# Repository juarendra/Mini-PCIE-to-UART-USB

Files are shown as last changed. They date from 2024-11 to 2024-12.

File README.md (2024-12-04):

# Mini-PCIE-to-UART-USB

## Table of Content

* [Product Specsification](#product-specsification)
* [Priview Hardware](#priview-hardware)
* [Documentation](#documentation)
  * [Pinout Diagram](#pinout-diagram)
  * [Dimension](#dimension)
  * [Schematic](#schematic)
* [FAQ](#FAQ)

## Product Spesification
* Mini PCIe Connector
* MIC29302WU as PSU 5V to 3V3
* USB Type C 
* 4 pin JST MOLEX 2.54 as Connector Serial
* LED INDICATOR
* Pin Control RST and WAKEUP

## Priview Hardware
<p align="center">
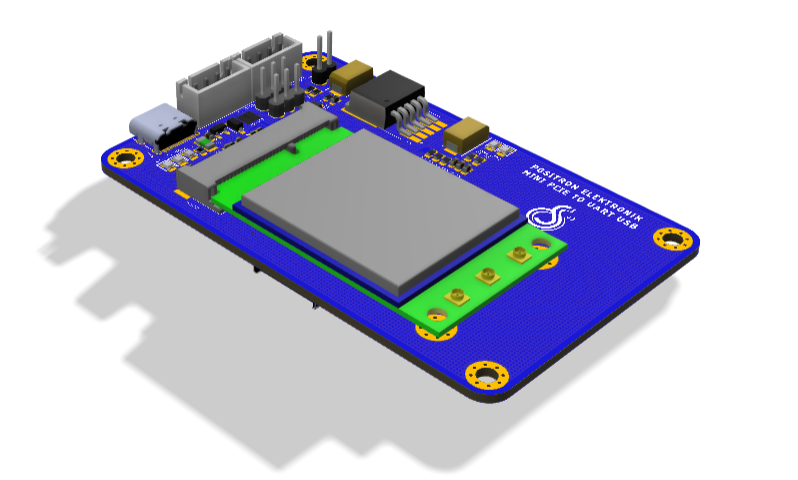
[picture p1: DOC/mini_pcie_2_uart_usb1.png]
  
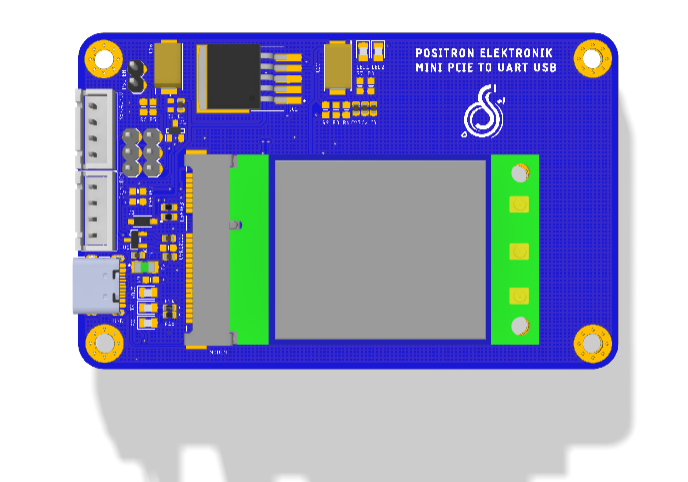
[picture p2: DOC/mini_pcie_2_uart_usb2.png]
  
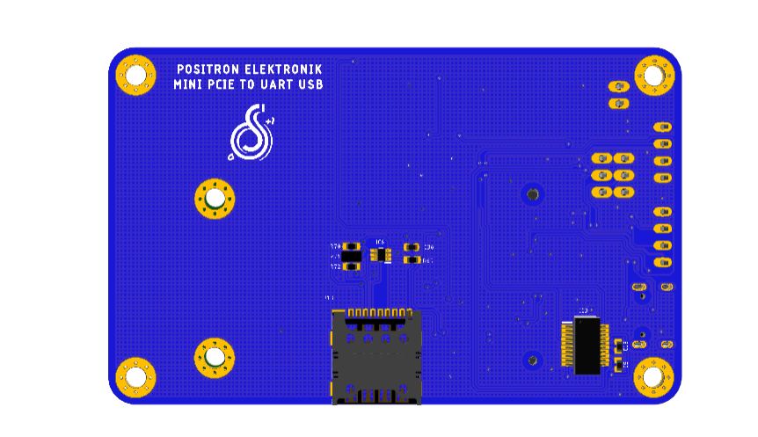
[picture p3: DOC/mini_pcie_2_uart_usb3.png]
  
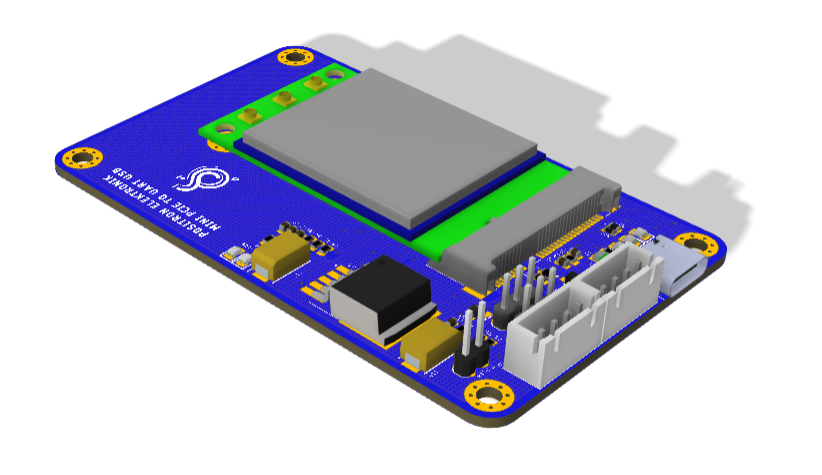
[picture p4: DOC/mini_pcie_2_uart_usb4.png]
  
</p>

## Documentation
### Pinout Diagram
* [Pinout](https://github.com/juarendra/Mini-PCIE-to-UART-USB/blob/main/DOC/Pinout%20Mini-PCIE-to-UART-USB.drawio.pdf)
### Dimension
* [Dimension Board with Component](https://github.com/juarendra/Mini-PCIE-to-UART-USB/blob/main/DOC/DIMENSION%20MINI%20PCIE%202UART%20USB.pdf)
### Schematic
* [Schematic](https://github.com/juarendra/Mini-PCIE-to-UART-USB/blob/main/PDF/mini_pcie_to_uart_usb.pdf)

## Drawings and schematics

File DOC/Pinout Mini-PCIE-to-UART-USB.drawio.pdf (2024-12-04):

# PINOUT CONNECTOR MINI PCIE TO UART USB

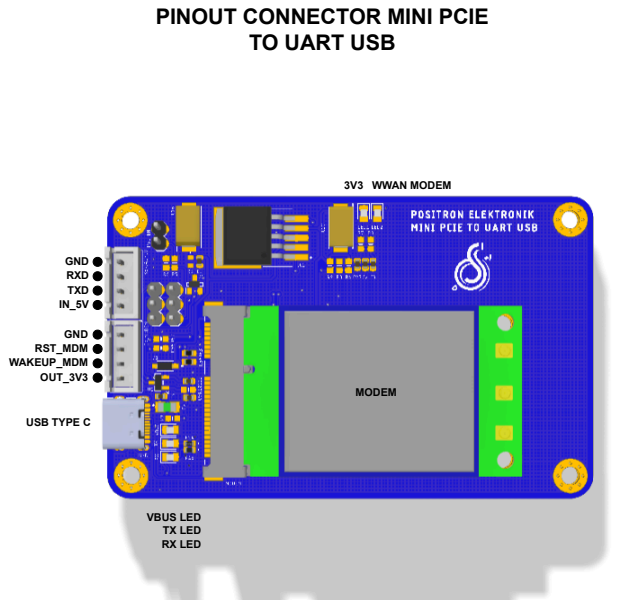
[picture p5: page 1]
GND RXD TXD IN_5V; GND RST_MDM WAKEUP_MDM OUT_3V3; USB TYPE C; VBUS LED TX LED RX LED; 3V3 WWAN MODEM; MODEM

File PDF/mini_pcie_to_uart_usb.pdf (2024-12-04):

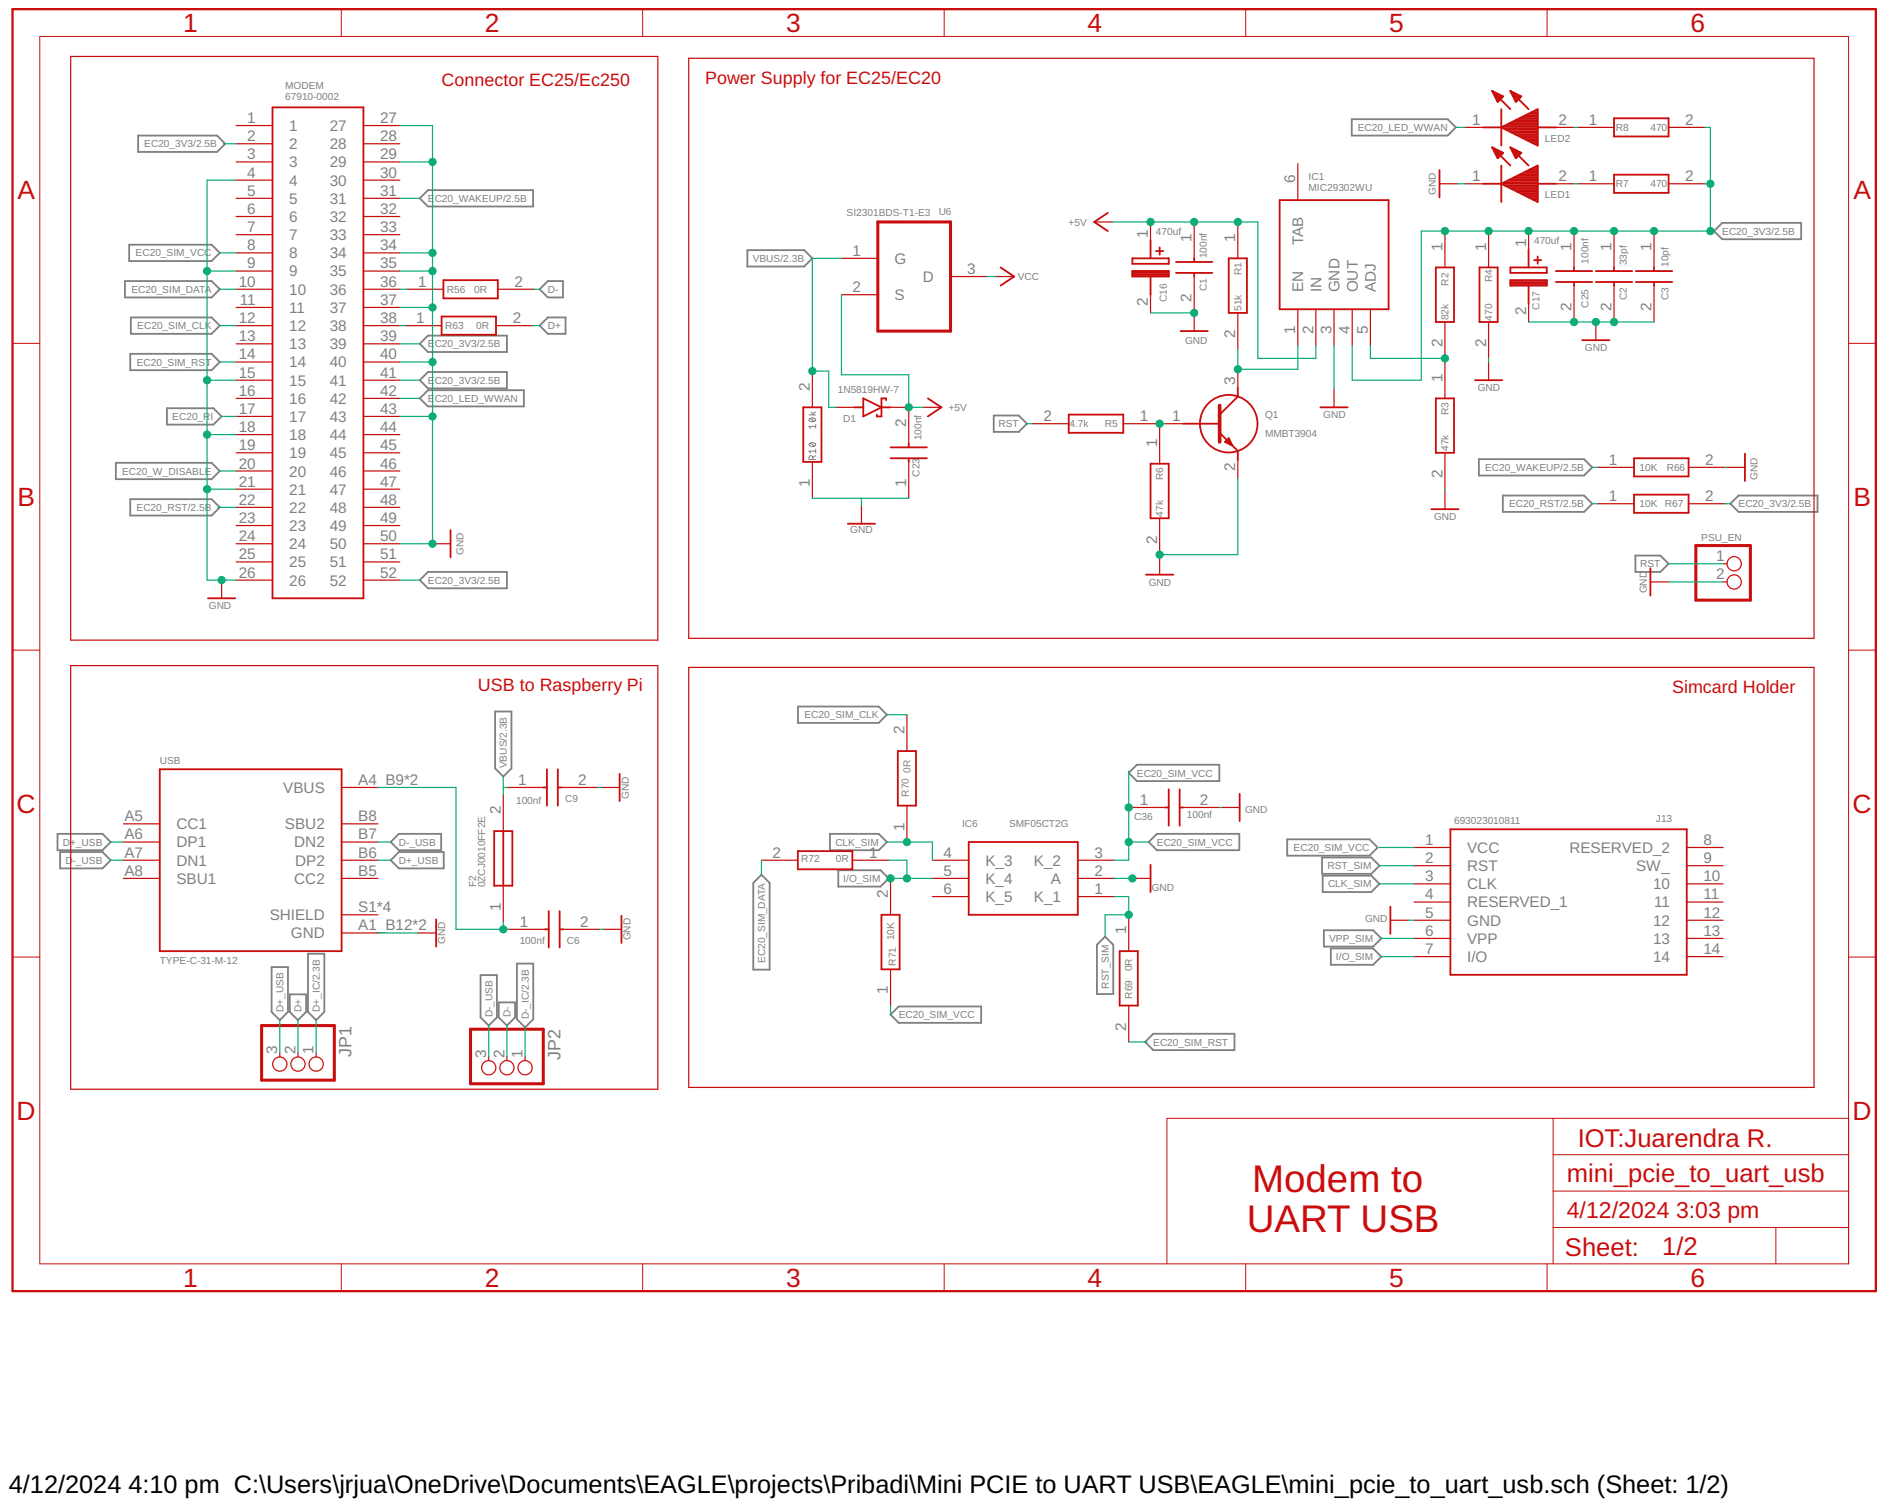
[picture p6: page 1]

4/12/2024 4:10 pm C:\Users\jrjua\OneDrive\Documents\EAGLE\projects\Pribadi\Mini PCIE to UART USB\EAGLE\mini_pcie_to_uart_usb.sch (Sheet: 1/2)

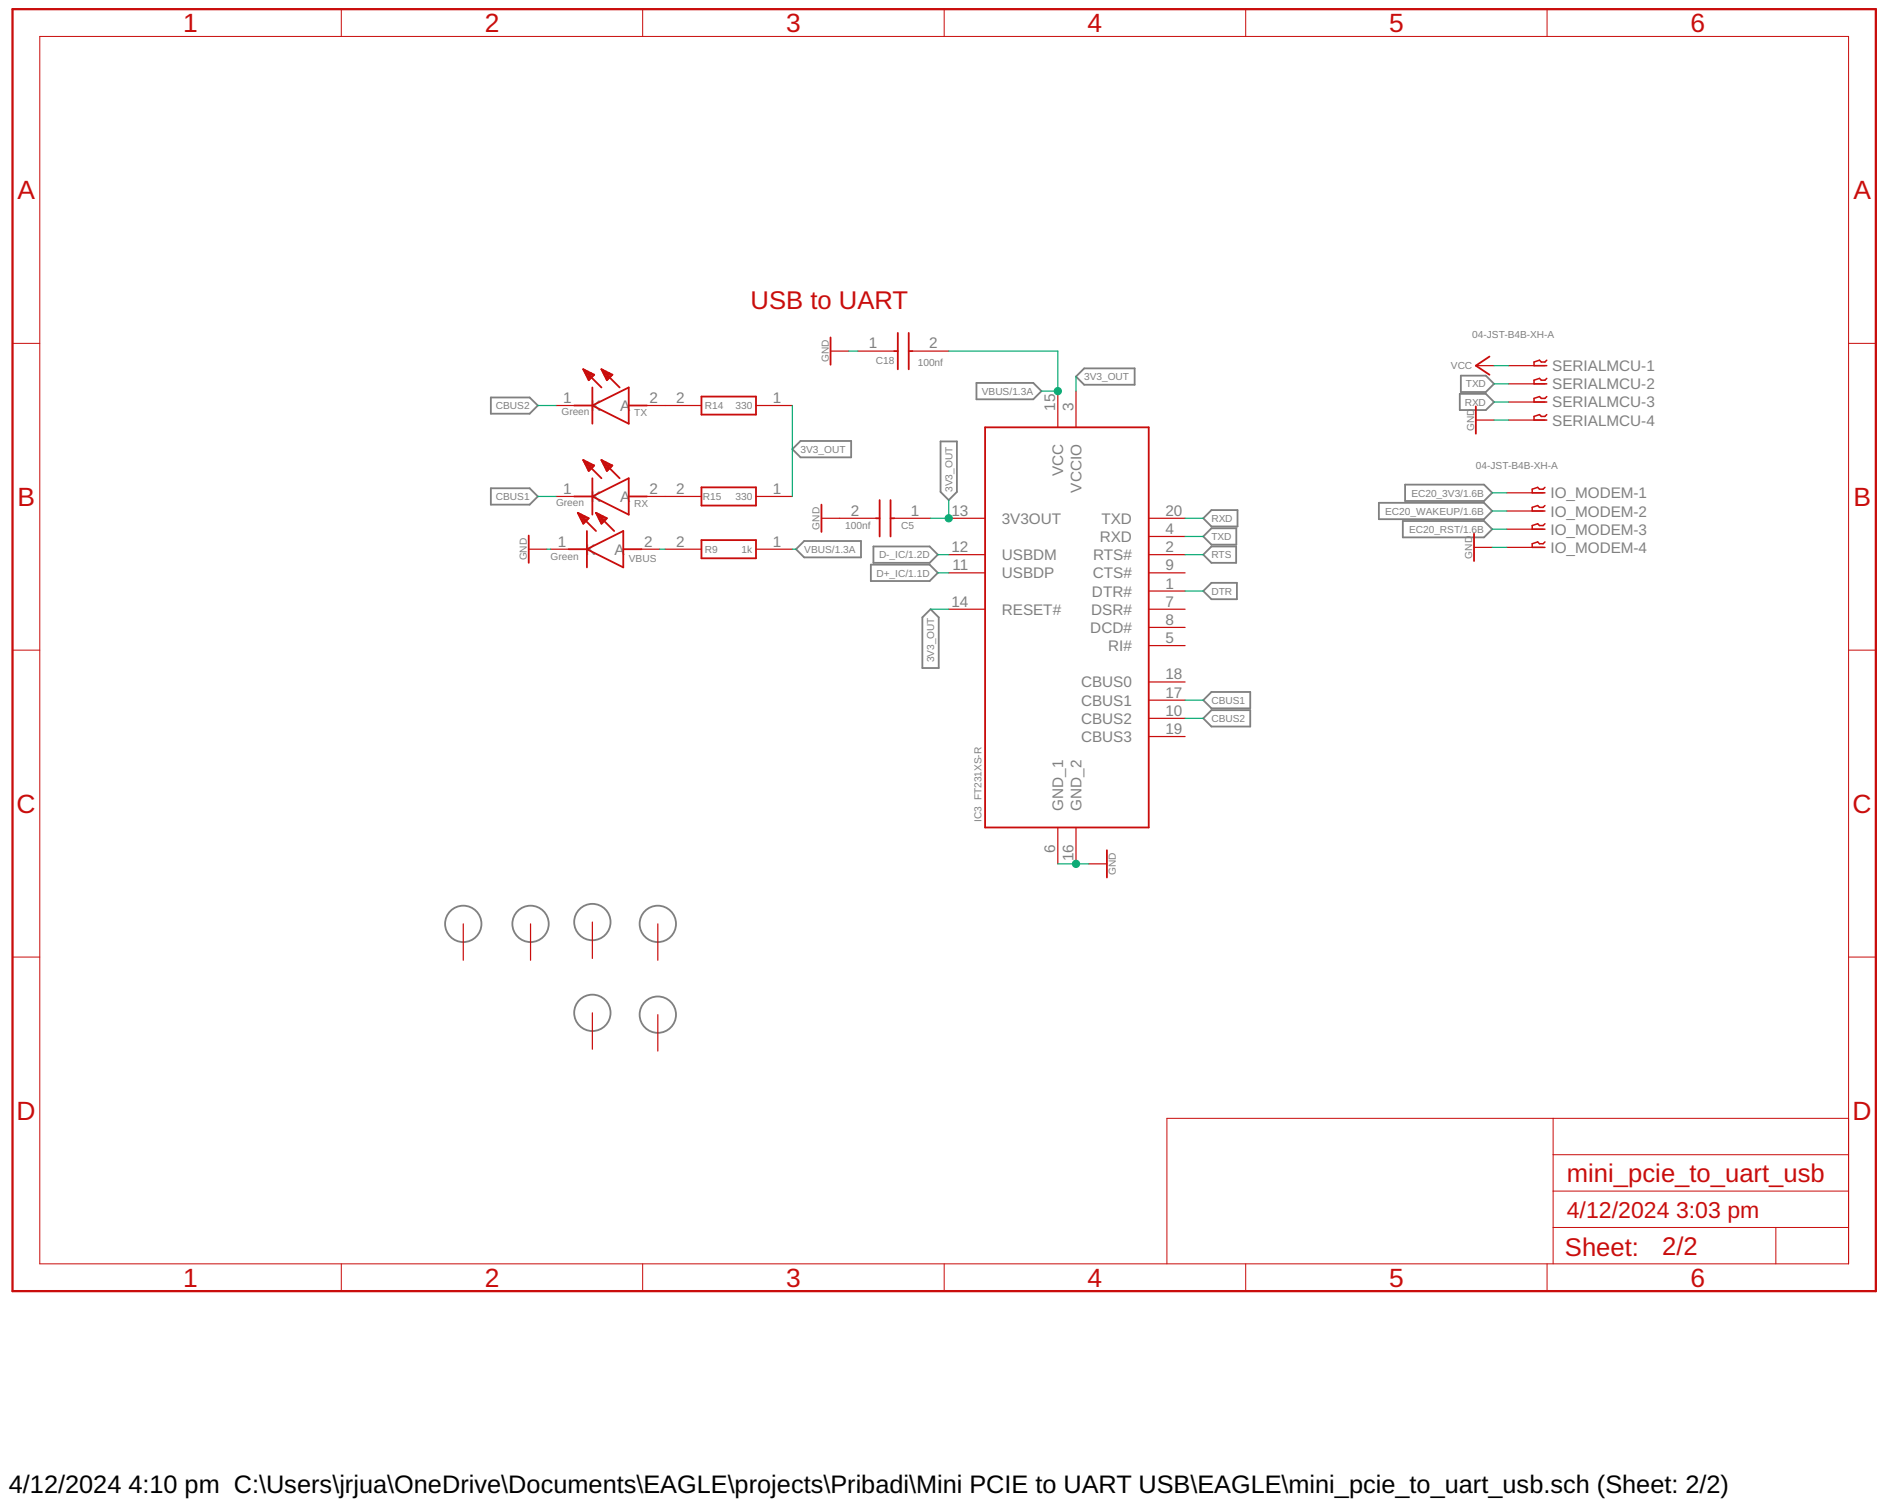
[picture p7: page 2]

SERIALMCU-1 SERIALMCU-2 SERIALMCU-3 SERIALMCU-4

4/12/2024 4:10 pm C:\Users\jrjua\OneDrive\Documents\EAGLE\projects\Pribadi\Mini PCIE to UART USB\EAGLE\mini_pcie_to_uart_usb.sch (Sheet: 2/2)

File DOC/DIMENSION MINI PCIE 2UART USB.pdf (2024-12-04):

# 53.59 Ø3.2 Ø3.2

1.57

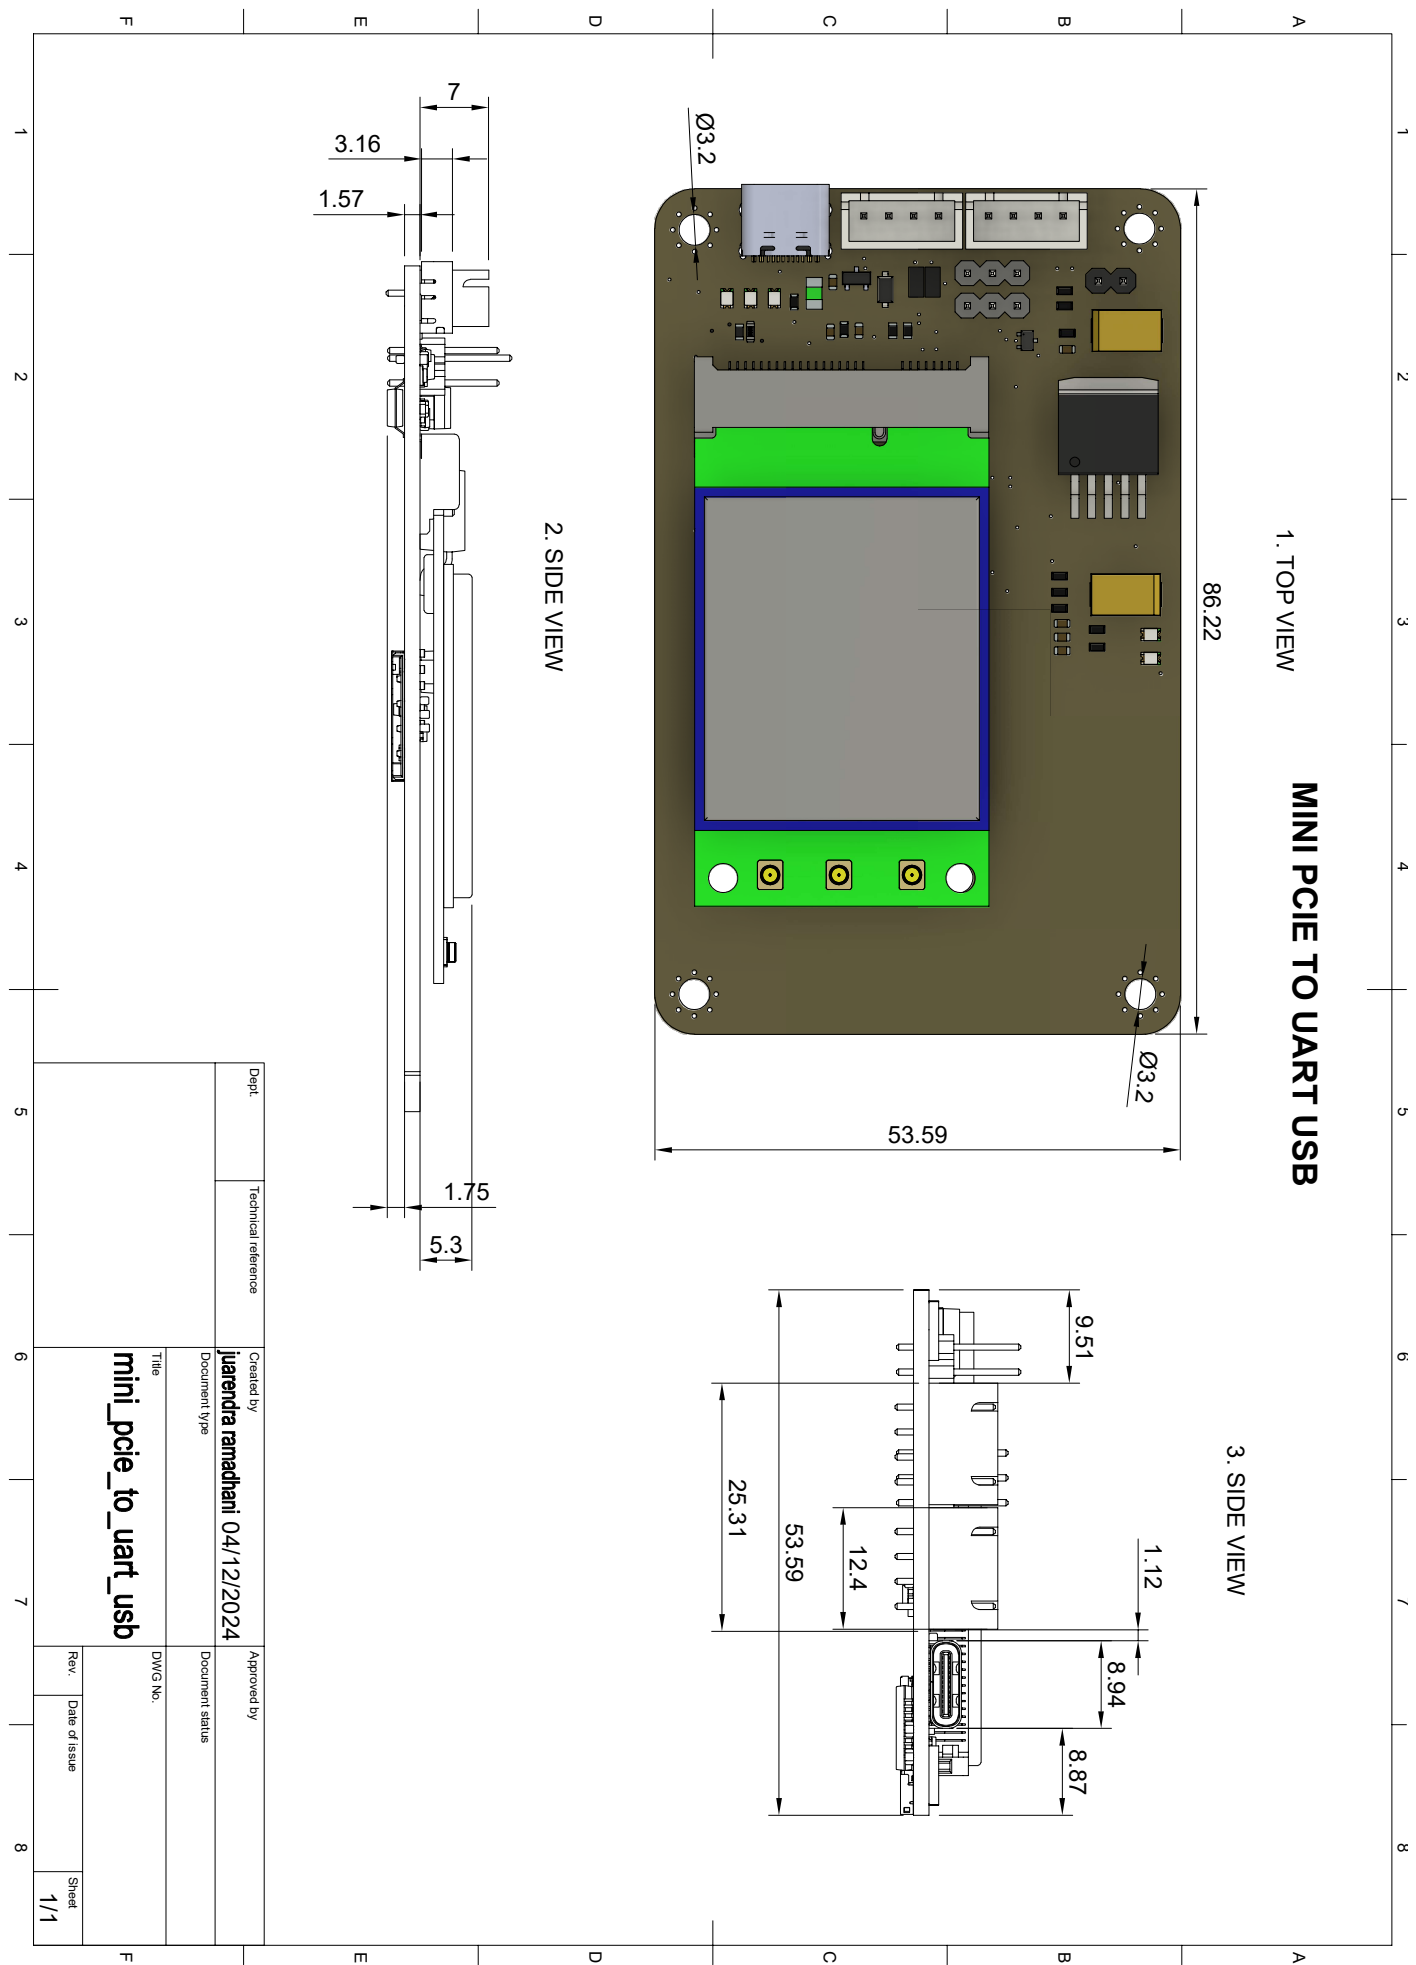
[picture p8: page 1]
9.51 25.31 2. SIDE VIEW; 1. TOP VIEW 3. SIDE VIEW; MINI PCIE TO UART USB

1 A 2 3 4 5 6 7 8 1 2 3 4 5 6 7 8 FEDCB FEDCBA Dept. Technical reference Created by Approved by Title DWG No. Document type Document status Rev. Date of issue Sheet 04/12/2024 1/1 86.22

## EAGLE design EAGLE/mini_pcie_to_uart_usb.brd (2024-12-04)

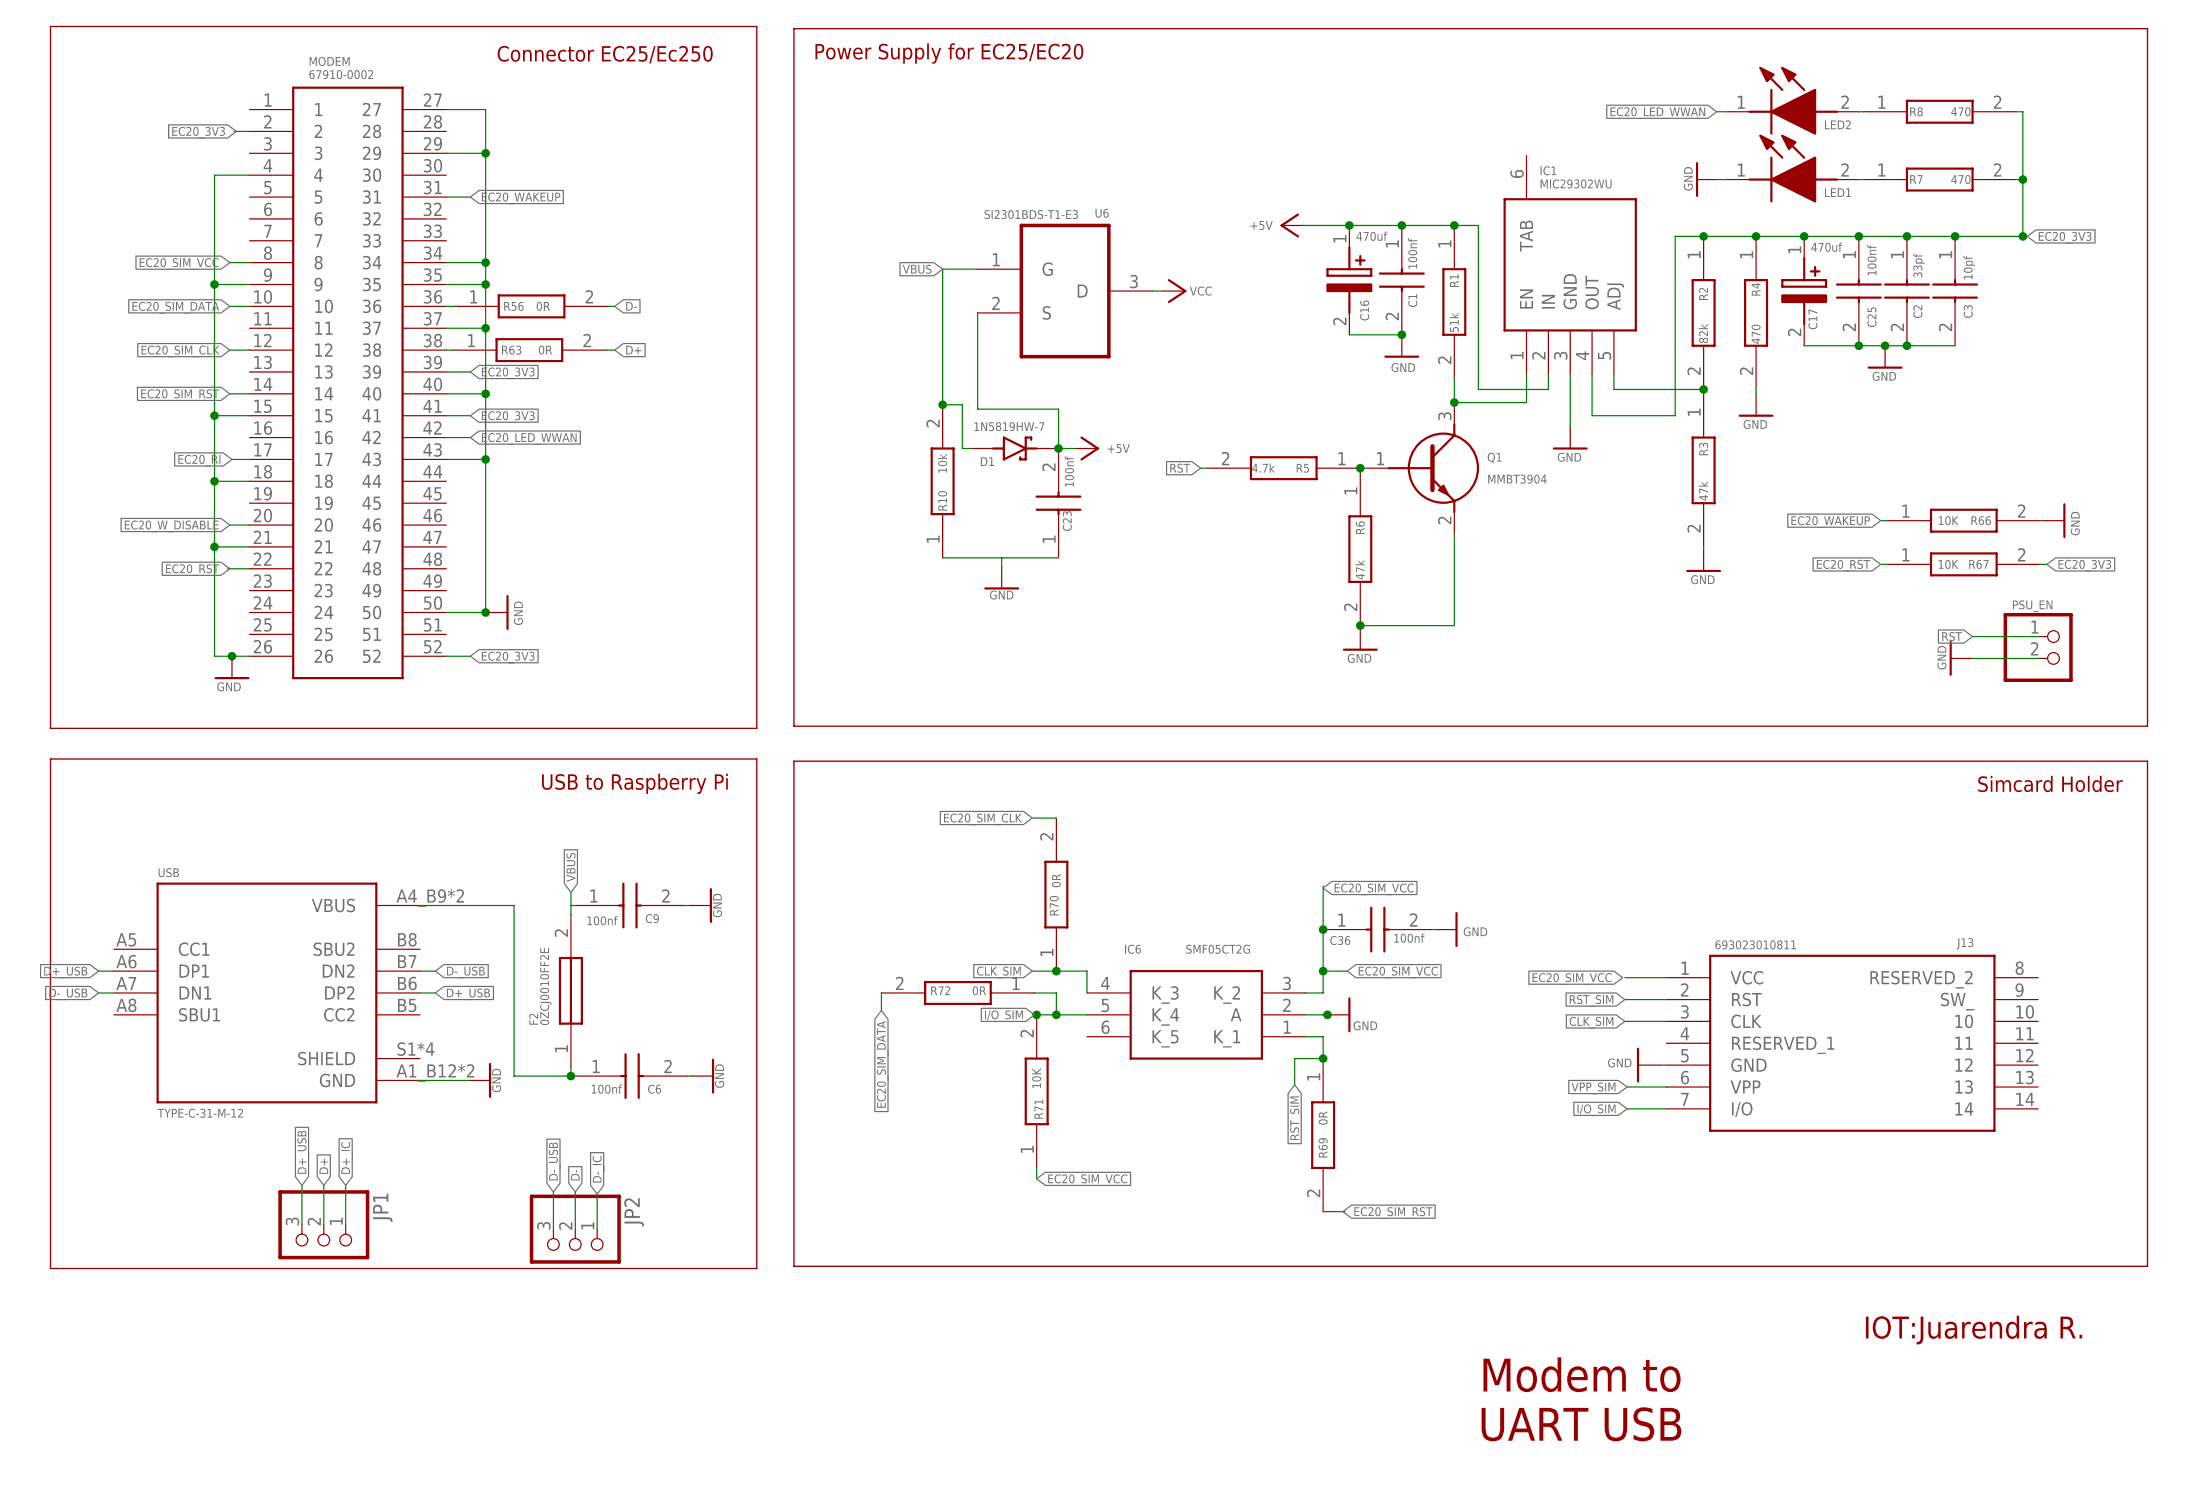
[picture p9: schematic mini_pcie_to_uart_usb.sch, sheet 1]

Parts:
C1, C25, C36: 100nf; CAPC1608X90N
C2: 33pf; CAPC1608X90N
C3: 10pf; CAPC1608X90N
C6, C9, C23: 100nf; CAPC1608X87N
C16, C17: 470uf; CAPPM7343X310N
D1: 1N5819HW-7; SOD3715X145N
F2: 0ZCJ0010FF2E; FUSC3216X75N
IC1: MIC29302WU
IC6: SMF05CT2G; SOT65P210X110-6N
J13: 693023010811
JP1, JP2: PINHD-1X3; 1X03
LED1, LED2: HSMR-C170-R0000; LEDC2012X90N
MODEM: 67910-0002; 67910-5700
PSU_EN: PINHD-1X2; 1X02
Q1: MMBT3904; SOT95P240X120-3N
R1: 51k; ERJP03_PA3_(0603)
R2: 82k; RESC1609X55N
R3, R6: 47k; RESC1609X55N
R4, R7, R8: 470; RESC1609X55N
R5: 4.7k; RESC1609X55N
R10: 10k; RESC1608X55N
R56, R63, R69, R70, R72: 0R; RESC1608X55N
R66, R67, R71: 10K; RESC1608X55N
U6: SI2301BDS-T1-E3; SOT95P237X112-3N
USB: TYPE-C-31-M-12; HRO_TYPE-C-31-M-12

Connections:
+5V: C1.1, C16.1 (+), C23.2, D1.C (K), IC1.2 (IN), R1.1, U6.2 (S)
CLK_SIM: IC6.4 (K_3), J13.3 (CLK), R70.1
D+: JP1.2, R63.2
D+_IC: JP1.1; also elsewhere on the board
D+_USB: JP1.3, USB.A6 (DP1), USB.B6 (DP2)
D-: JP2.2, R56.2
D-_IC: JP2.1; also elsewhere on the board
D-_USB: JP2.3, USB.A7 (DN1), USB.B7 (DN2)
EC20_3V3: C2.1, C3.1, C17.1 (+), C25.1, IC1.4 (OUT), MODEM.2, MODEM.39, MODEM.41, MODEM.52, R2.1, R4.1, R7.2, R8.2, R67.2; also elsewhere on the board
EC20_LED_WWAN: LED2.1 (K), MODEM.42
EC20_RI: MODEM.17
EC20_RST: MODEM.22, R67.1; also elsewhere on the board
EC20_SIM_CLK: MODEM.12, R70.2
EC20_SIM_DATA: MODEM.10, R72.2
EC20_SIM_RST: MODEM.14, R69.2
EC20_SIM_VCC: C36.1, IC6.3 (K_2), J13.1 (VCC), MODEM.8, R71.1
EC20_WAKEUP: MODEM.31, R66.1; also elsewhere on the board
EC20_W_DISABLE: MODEM.20
GND: C1.2, C2.2, C3.2, C6.2, C9.2, C16.2 (-), C17.2 (-), C23.1, C25.2, C36.2, IC1.3 (GND), IC6.2 (A), J13.5 (GND), LED1.1 (K), MODEM.4, MODEM.9, MODEM.15, MODEM.18, MODEM.21, MODEM.26, MODEM.27, MODEM.29, MODEM.34, MODEM.35, MODEM.37, MODEM.40, MODEM.43, MODEM.50, PSU_EN.2, Q1.2 (E), R3.2, R4.2, R6.2, R10.1, R66.2, USB.A1_B12 (GND), USB.B1_A12 (GND); also elsewhere on the board
I/O_SIM: IC6.5 (K_4), J13.7 (I/O), R71.2, R72.1
unnamed: IC1.1 (EN), Q1.3 (C), R1.2
unnamed: IC1.5 (ADJ), R2.2, R3.1
unnamed: Q1.1 (B), R5.1, R6.1
unnamed: LED1.2 (A), R7.1
unnamed: C6.1, F2.1, USB.A4_B9 (VBUS), USB.B4_A9 (VBUS)
unnamed: LED2.2 (A), R8.1
unnamed: MODEM.38, R63.1
unnamed: MODEM.36, R56.1
RST: PSU_EN.1, R5.2
RST_SIM: IC6.1 (K_1), J13.2 (RST), R69.1
VBUS: C9.1, D1.A, F2.2, R10.2, U6.1 (G); also elsewhere on the board
VCC: U6.3 (D); also elsewhere on the board
VPP_SIM: J13.6 (VPP)

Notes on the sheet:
Modem to UART USB
IOT:Juarendra R.
USB to Raspberry Pi
Simcard Holder
Power Supply for EC25/EC20
Connector EC25/Ec250

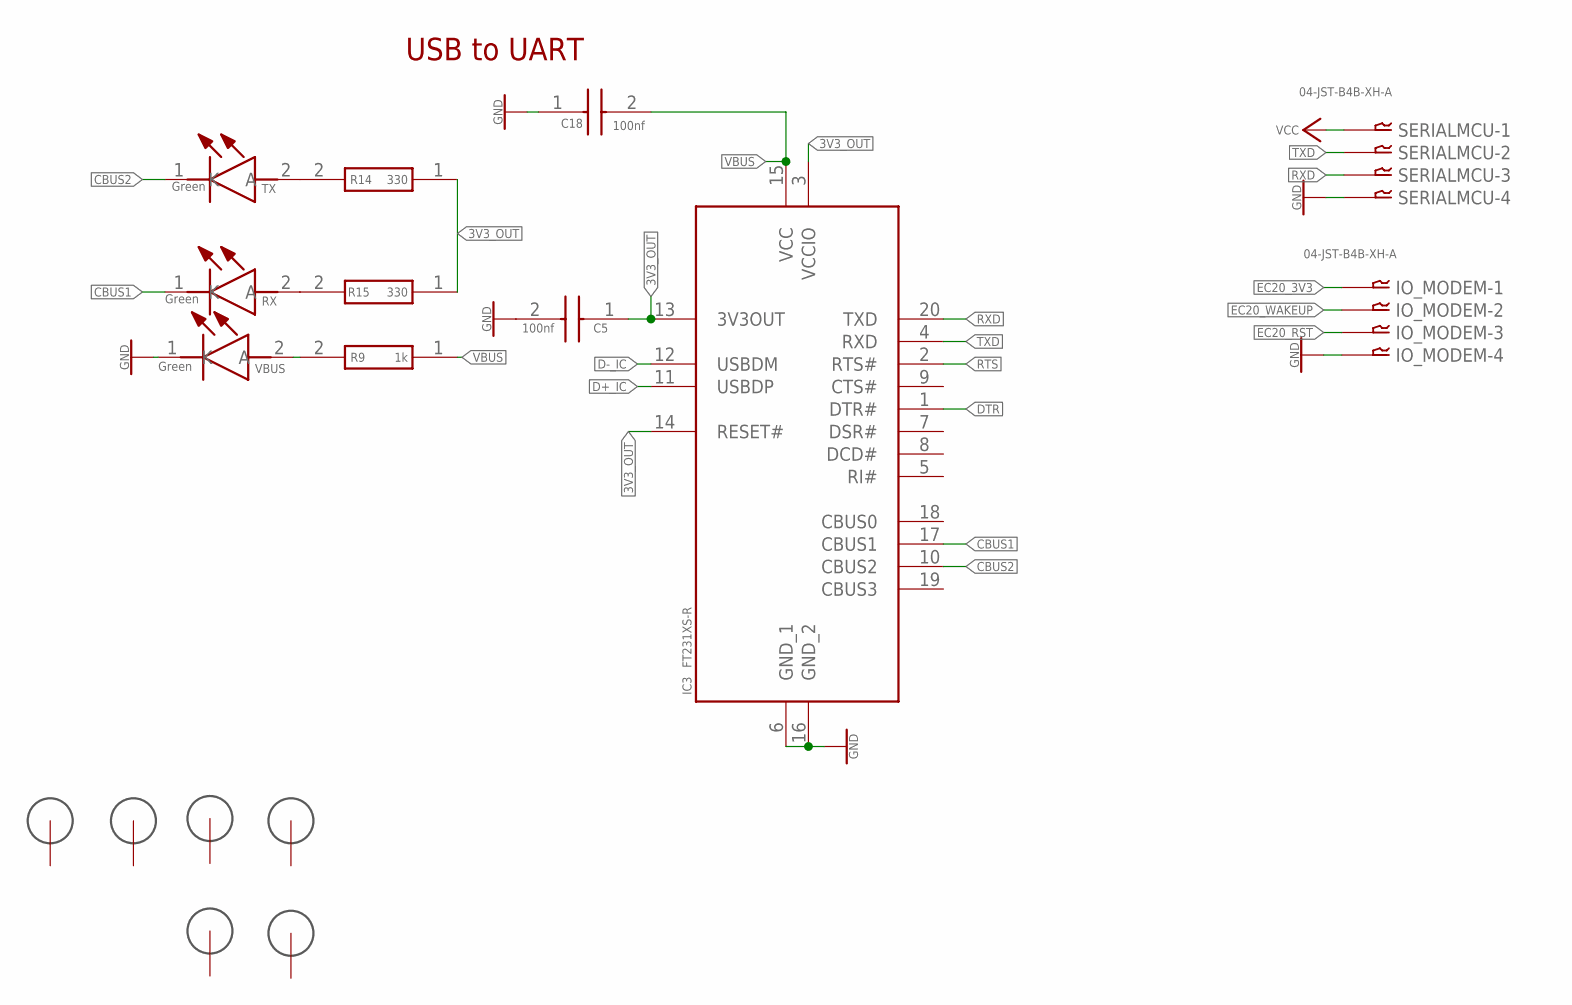
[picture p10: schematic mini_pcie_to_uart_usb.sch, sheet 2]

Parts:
C5, C18: 100nf; CAPC1608X87N
H1, H2, H3, H4, H5, H6: 3MM_HOLE
IC3: FT231XS-R; SOP64P599X175-20N
IO_MODEM: 04-JST-B4B-XH-A; B4B-XH
R9: 1k; RESC1608X55N
R14, R15: 330; ERJH3
RX: Green; LEDC2012X80N
SERIALMCU: 04-JST-B4B-XH-A; B4B-XH
TX: Green; LEDC2012X80N
VBUS: Green; LEDC2012X80N

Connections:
3V3_OUT: C5.1, IC3.3 (VCCIO), IC3.13 (3V3OUT), IC3.14 (RESET#), R14.1, R15.1
CBUS1: IC3.17 (CBUS1), RX.1 (K)
CBUS2: IC3.10 (CBUS2), TX.1 (K)
D+_IC: IC3.11 (USBDP); also elsewhere on the board
D-_IC: IC3.12 (USBDM); also elsewhere on the board
DTR: IC3.1 (DTR#)
EC20_3V3: IO_MODEM.P$1; also elsewhere on the board
EC20_RST: IO_MODEM.P$3; also elsewhere on the board
EC20_WAKEUP: IO_MODEM.P$2; also elsewhere on the board
GND: C5.2, C18.1, IC3.6 (GND_1), IC3.16 (GND_2), IO_MODEM.P$4, SERIALMCU.P$4, VBUS.1 (K); also elsewhere on the board
unnamed: R15.2, RX.2 (A)
unnamed: R9.2, VBUS.2 (A)
unnamed: R14.2, TX.2 (A)
RTS: IC3.2 (RTS#)
RXD: IC3.20 (TXD), SERIALMCU.P$3
TXD: IC3.4 (RXD), SERIALMCU.P$2
VBUS: C18.2, IC3.15 (VCC), R9.1; also elsewhere on the board
VCC: SERIALMCU.P$1; also elsewhere on the board

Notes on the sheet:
USB to UART

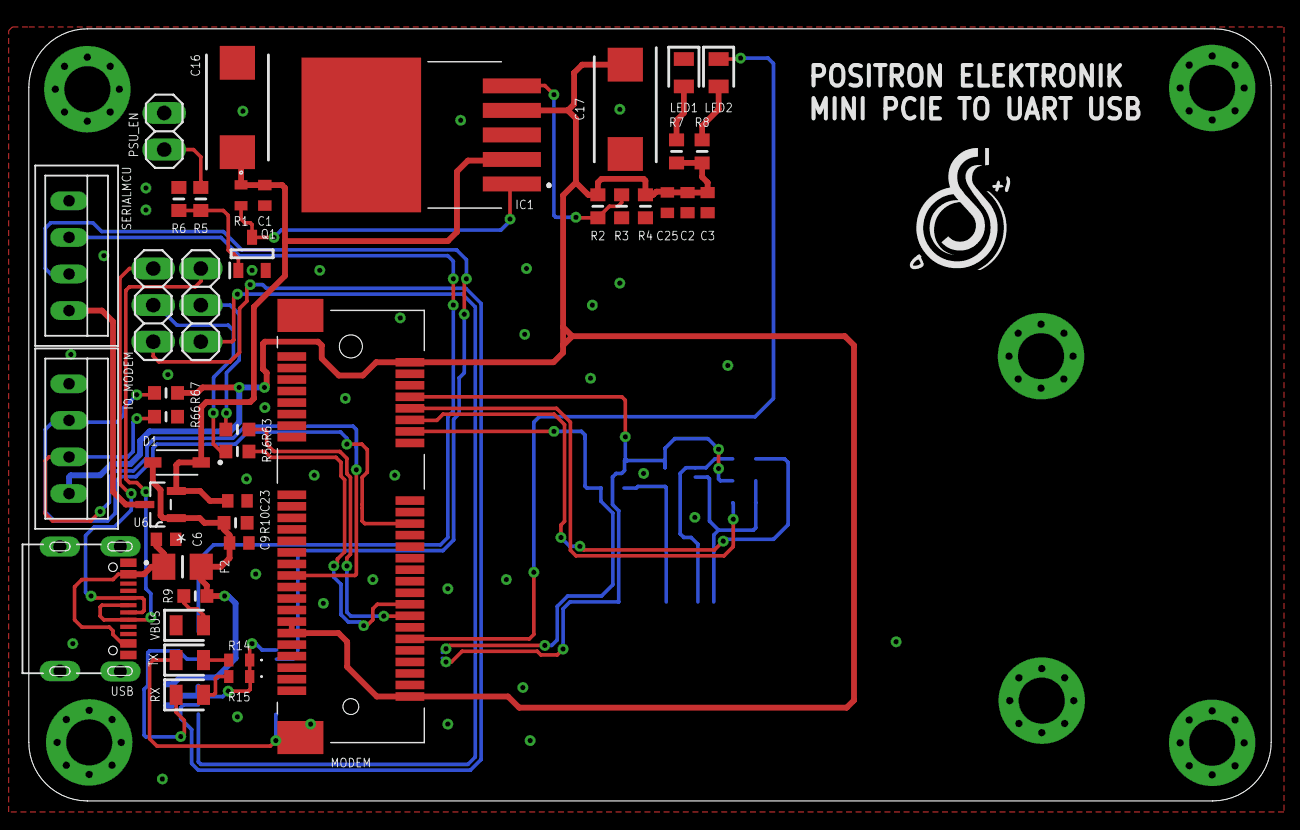
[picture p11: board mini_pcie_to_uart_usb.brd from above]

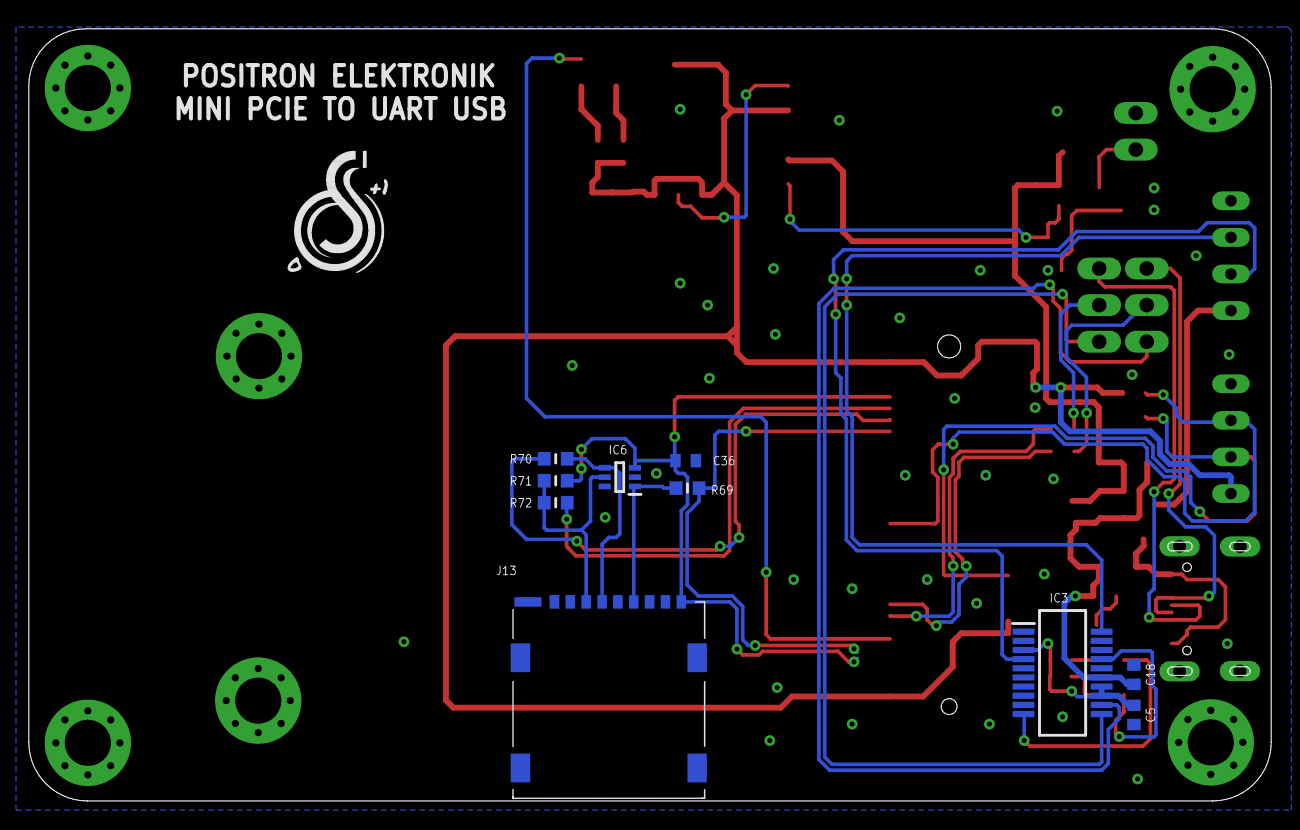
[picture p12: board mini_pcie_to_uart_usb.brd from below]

Board: 2 copper layers, 86.2 x 53.6 mm, 58 parts (10 on the bottom side), 38 nets.

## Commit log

2024-11-29 FEAT: add psu switchover
2024-11-30 FEAT: add connector to mcu
    [untitled.sch]
2024-11-30 FEAT: update layout pcb
    [untitled.brd, untitled.sch]
2024-11-30 FEAT: update route pcb
    [untitled.brd, untitled.sch]
2024-12-04 FEAT: update 3d pcb
    [mini_pcie_to_uart_usb.brd, mini_pcie_to_uart_usb.sch, untitled.sch]
2024-12-04 FEAT: update pcb and file documentation
    [mini_pcie_to_uart_usb.brd]
2024-12-04 FEAT: add schematic
2024-12-04 DOC: update documentation link schematic
